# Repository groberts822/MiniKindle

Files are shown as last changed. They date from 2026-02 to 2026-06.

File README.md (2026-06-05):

# MiniKindle
A mini e-reader/kindle!
---
Final Design:





Final Build:



Demo:

https://youtube.com/shorts/sy03gHUxKEQ 

CAD Models:



Note for the CAD design. There are holes to connect the wires from the switch and TP4056 (the pos and neg) to the pins of the ESP32C3, its just hard to get a good picture of those. Also, the battery setup will be soldered to the 5V and GND pins of the microcontroller as the battery pads are covered by the case, and its simply easier to access the 5V pin, which works just fine as it can take the 3.7V down to the 3.3V fine.

Another note, the case will be assembled by using super glue to secure all 3D printed parts to one another. The PCB fits right into place and (should) fit securely enough to keep it in place without wiggling. 

Assembly:



Just a note, the eink display will be mounted to the board through the pins for the white connector. It may seem overly complicated, but i've done it for projects before and it's easier than it seems. It will simply be soldered from the pins there to the soldering holes using wires, as there isnt really an easier, compact way to connect it, and I just prefer this method.

Schematic:



PCB: 



3D of PCB with all Parts





Bill of Materials (also in .csv format)

| Item | Order Qty | Actual Amount Needed | Link |
|---|---|---|---|
| Seeed Studio XIAO ESP32C3 | 1 | 1 | [Amazon](https://www.amazon.com/Seeed-Studio-XIAO-ESP32C3-Microcontroller/dp/B0B94JZ2YF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) |
| Waveshare 2.13in E-Ink Display HAT | 1 | 1 | [Amazon](https://www.amazon.com/waveshare-2-13inch-HAT-Compatible-Resolution/dp/B071S8HT76/) |
| ANMBEST Micro SD Card Adapter | 1 pack (10pcs) | 1 | [Amazon](https://www.amazon.com/ANMBEST-Adapter-Interface-Conversion-Arduino/dp/B08CMLG4D6/) |
| DAOKI 6mm Tactile Push Buttons | 1 pack (100pcs) | 2 | [Amazon](https://www.amazon.com/DAOKI-Miniature-Momentary-Tactile-Quality/dp/B01CGMP9GY/) |
| MakerFocus 3.7V 1100mAh LiPo Battery | 1 pack (4pcs) | 1 | [Amazon](https://www.amazon.com/1100mAh-Rechargable-Protection-Insulated-Development/dp/B0867KDMY7/) |
| ALAMSCN TP4056 Type-C Charger | 1 pack (12pcs) | 1 | [Amazon](https://www.amazon.com/ALAMSCN-Lithium-Charging-Protection-Functions/dp/B08F7QSLN7/) |
| Mini Micro Slide Switch | 1 pack (20pcs) | 1 | [Amazon](https://www.amazon.com/Mini-Micro-Slide-Switch-Breadboard/dp/B0DN69L9SG/) |

------------------------------------------------------
I wanted a reading device which didn't feel like a smartphone. Most modern screens are meant to grab our attention with the backlight and notifications. This project is about the opposite, being a distraction-free and almost "offline" experience. This project uses an E-ink display and the text looks like actuasl paper and doesn't strain the eyes. Plus since the E-ink only uses power when the page changes initially, I can leave a book open for long periods of time without the battery dying. 

The brain of the project is a XIAO ESP32C3. When you flip the physical slide switch the system boots and reads the book files (.txt files) from the MicroSD card. There are 2 tactile buttons which allow you to essentially turn the page. It uses a 2.13-in electronic paper display (EPD) and is crisp in direct sunlight and stays on/displays text even after power is cut. A TP4056 module manages the 1100mAh LiPo battery, which you can charge via USB-C, and the slide switch makes sure the battery doesnt drain when the reader is not in use.

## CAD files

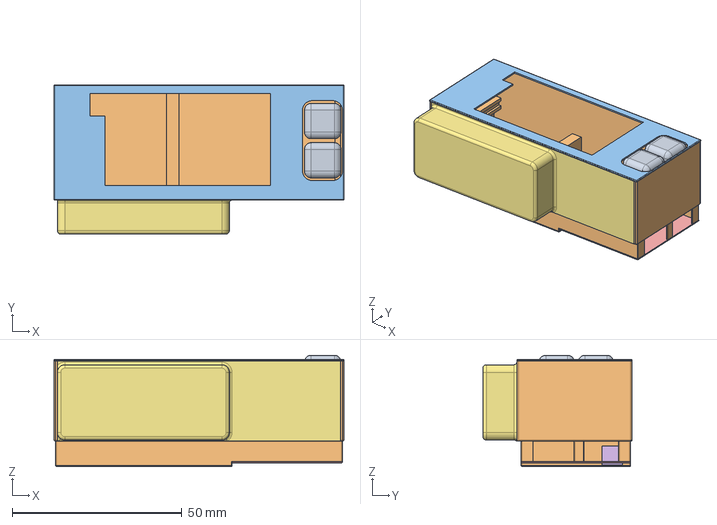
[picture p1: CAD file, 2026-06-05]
cad/Mini Kindle Assembled (No PCB or Parts).step
85.5 x 44.0 x 32.9 mm
SW_PUSH_6mm x 2

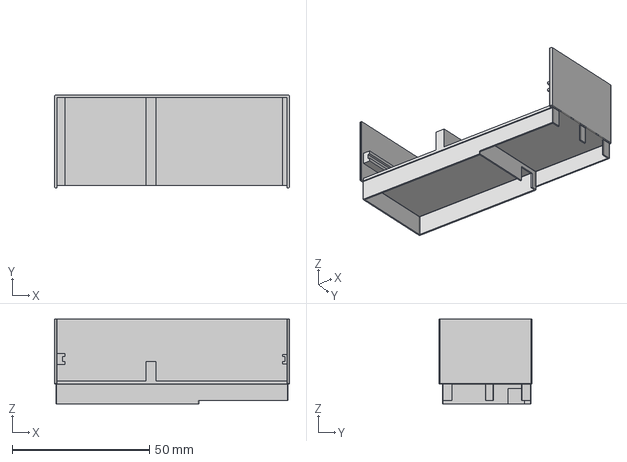
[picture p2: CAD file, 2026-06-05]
cad/Mini Kindle Main Body.step
85.5 x 34.0 x 30.8 mm

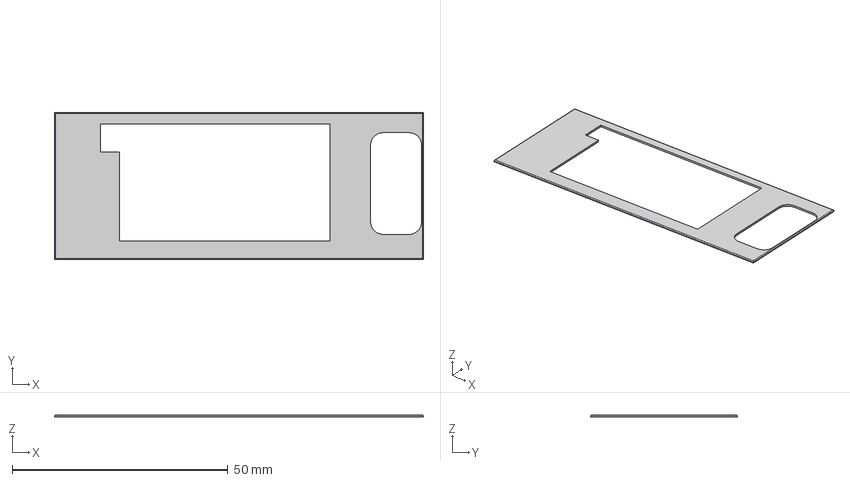
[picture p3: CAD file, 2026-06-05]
cad/Mini Kindle Top Cover.step
85.5 x 34.0 x 0.5 mm

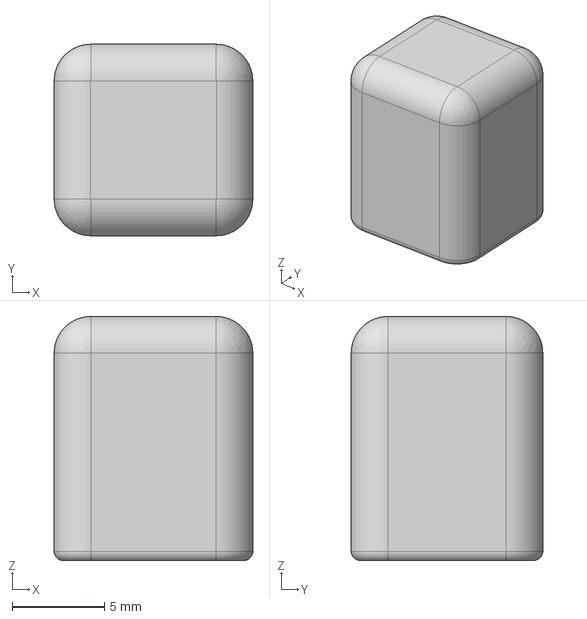
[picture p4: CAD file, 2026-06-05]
cad/Mini Kindle Button Cap.step
10.8 x 10.4 x 13.3 mm

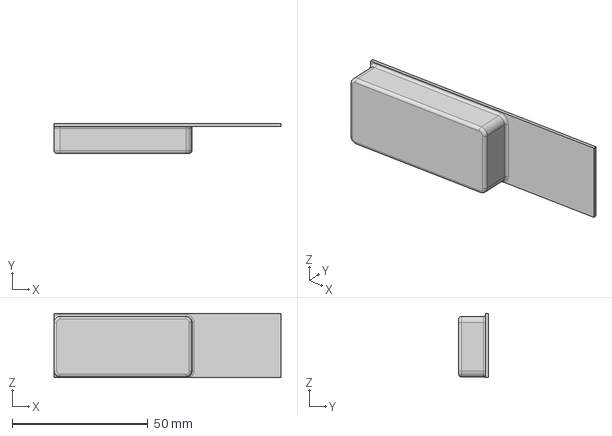
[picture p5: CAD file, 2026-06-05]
cad/Mini Kindle Front Side Cover.step
83.5 x 11.0 x 23.5 mm

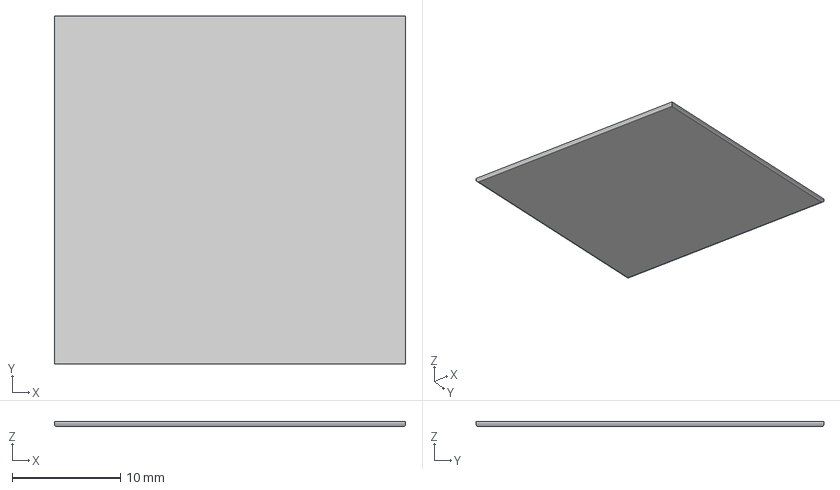
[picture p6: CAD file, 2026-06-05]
cad/Mini Kindle Switch + Charger Cover.step
32.5 x 32.2 x 0.5 mm

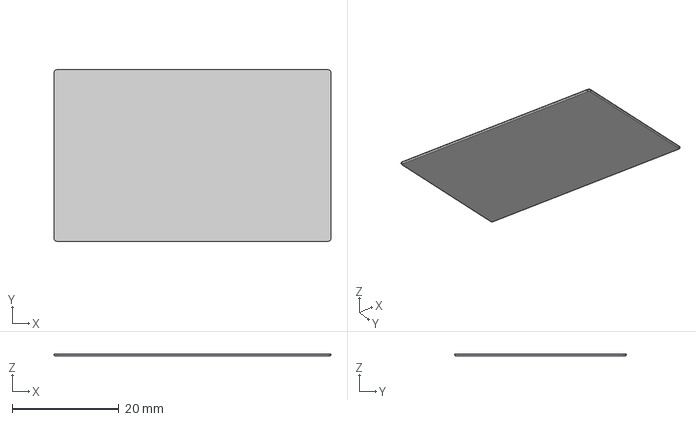
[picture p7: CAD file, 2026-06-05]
cad/Mini Kindle Battery Cover.step
52.0 x 32.2 x 0.4 mm

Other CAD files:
cad/Mini Kindle Assembled (No PCB or Parts).f3z
cad/Mini Kindle Assembled (with PCB + Parts).f3z

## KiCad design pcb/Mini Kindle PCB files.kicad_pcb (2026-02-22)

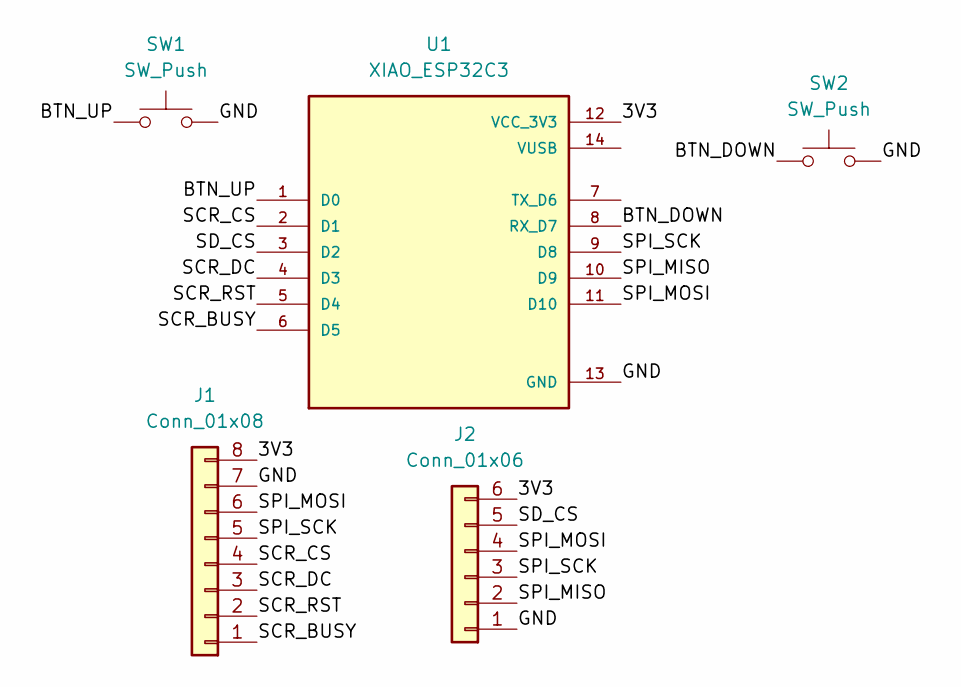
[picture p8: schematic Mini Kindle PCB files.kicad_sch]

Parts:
J1: Conn_01x08; PinHeader_1x08_P2.54mm_Vertical
J2: Conn_01x06; PinHeader_1x06_P2.54mm_Vertical
SW1, SW2: SW_Push; SW_PUSH_6mm
U1: XIAO_ESP32C3; MODULE_XIAO_ESP32C3; PARTREV 23/05/2022

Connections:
/3V3: J1.8, J2.6, U1.12 (VCC_3V3)
/BTN_DOWN: SW2.1, U1.8 (RX_D7)
/BTN_UP: SW1.1, U1.1 (D0)
/GND: J1.7, J2.1, SW1.2, SW2.2, U1.13 (GND)
/SCR_BUSY: J1.1, U1.6 (D5)
/SCR_CS: J1.4, U1.2 (D1)
/SCR_DC: J1.3, U1.4 (D3)
/SCR_RST: J1.2, U1.5 (D4)
/SD_CS: J2.5, U1.3 (D2)
/SPI_MISO: J2.2, U1.10 (D9)
/SPI_MOSI: J1.6, J2.4, U1.11 (D10)
/SPI_SCK: J1.5, J2.3, U1.9 (D8)

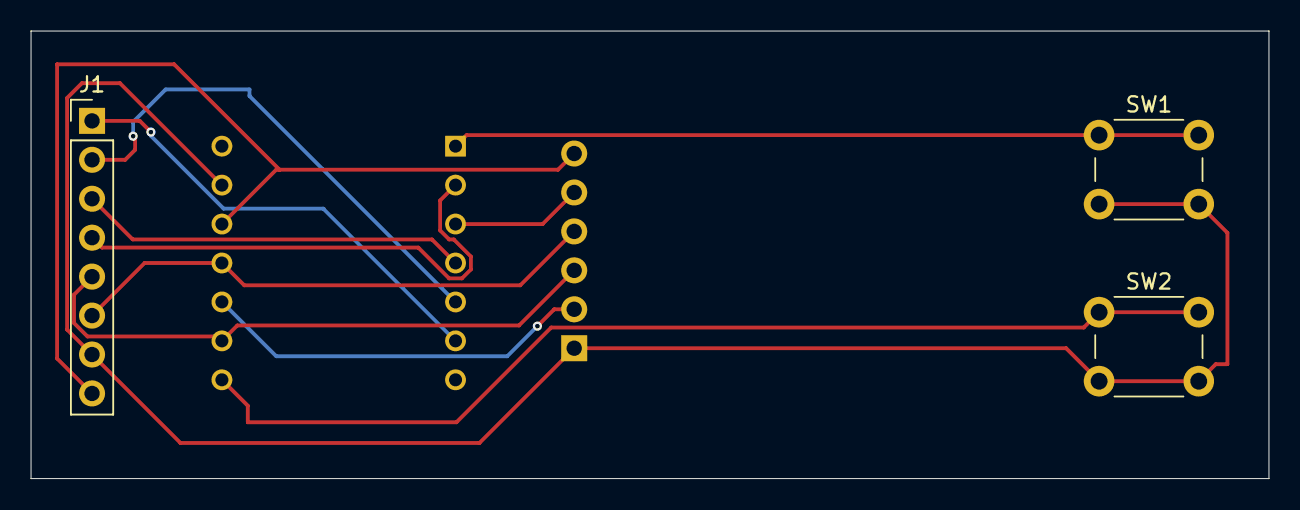
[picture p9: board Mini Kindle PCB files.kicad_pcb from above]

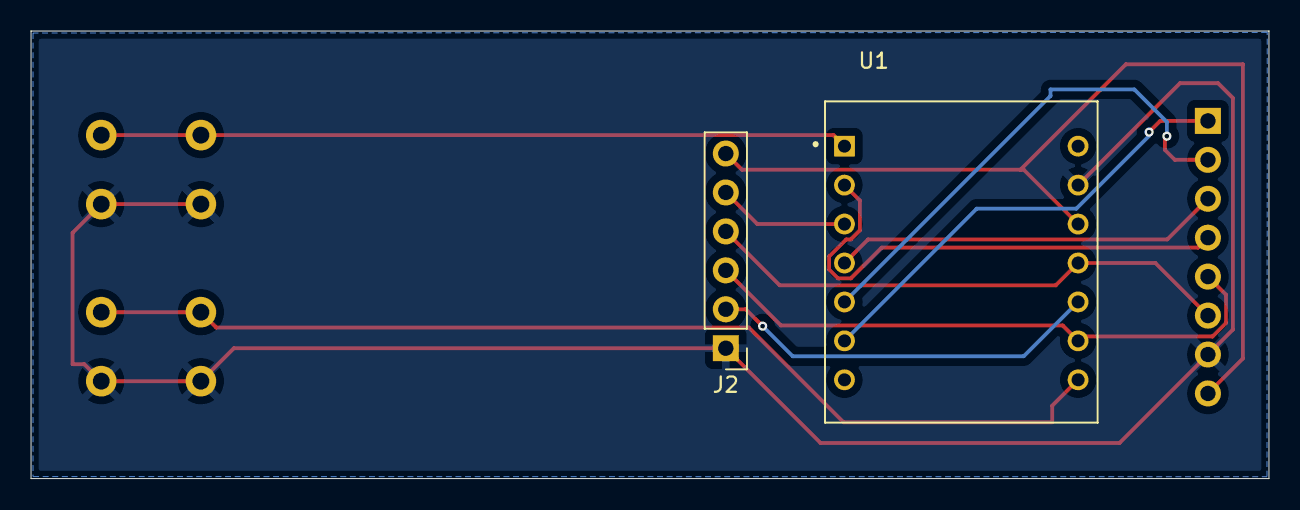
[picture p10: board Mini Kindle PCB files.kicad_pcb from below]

Board: 2 copper layers, 80.8 x 29.2 mm, 5 parts (2 on the bottom side), 12 nets.

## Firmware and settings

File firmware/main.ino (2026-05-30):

#include <GxEPD2_BW.h>
#include <SD.h>
#include <SPI.h>

#define SCREEN_CS   3
#define SCREEN_DC   5
#define SCREEN_RST  6
#define SCREEN_BUSY 7
#define SD_CS       4
#define SPI_MOSI    10
#define SPI_MISO    9
#define SPI_SCK     8
#define BTN_UP      2
#define BTN_DOWN    20

GxEPD2_BW<GxEPD2_213_BN, GxEPD2_213_BN::HEIGHT> display(
  GxEPD2_213_BN(SCREEN_CS, SCREEN_DC, SCREEN_RST, SCREEN_BUSY)
);

#define DISP_W 250
#define DISP_H 122

static const int ENTRY_ROW_TOP[6] = {14, 28, 42, 56, 70, 84};
static const int ENTRY_TEXT_Y[6]  = {17, 31, 45, 59, 73, 87};
#define MENU_ENTRIES   6
#define HDR_H         12
#define HDR_TY         2
#define HINT_TOP     112
#define HINT_TY      113

#define CHARS_PER_LINE 41
#define LINES_PER_PAGE 10
#define READ_LINE_H    11
#define READ_FIRST_Y    1
#define SCROLL_STEP     3

#define MAX_BOOKS 20
char bookNames[MAX_BOOKS][44];
char bookFiles[MAX_BOOKS][48];
int  bookCount   = 0;
int  menuIndex   = 0;
int  menuScroll  = 0;
int  readingBook = -1;

File bookFile;
long pageStart     = 0;
long prevPageStart = 0;

#define HOLD_MS     1800
#define DEBOUNCE_MS  30

struct Btn {
  bool     lastRaw;
  bool     confirmed;
  uint32_t downAt;
  bool     holdFired;
} bUp={}, bDown={};

uint8_t pollBtn(int pin, Btn &s) {
  bool raw = (digitalRead(pin) == LOW);

  if (raw && !s.lastRaw) {
    s.downAt    = millis();
    s.confirmed = false;
    s.holdFired = false;
  }

  if (raw && !s.confirmed && (millis() - s.downAt > DEBOUNCE_MS)) {
    s.confirmed = true;
  }

  if (s.confirmed && !s.holdFired && (millis() - s.downAt >= HOLD_MS)) {
    s.holdFired = true;
    s.lastRaw   = raw;
    return 2;
  }

  if (!raw && s.lastRaw) {
    bool fire = s.confirmed && !s.holdFired;
    s.confirmed = false;
    s.holdFired = false;
    s.lastRaw   = false;
    return fire ? 1 : 0;
  }

  s.lastRaw = raw;
  return 0;
}

void stemToTitle(const char *stem, char *out, int maxLen) {
  int i = 0;
  while (stem[i] && i < maxLen - 1) {
    out[i] = (stem[i] == '_') ? ' ' : stem[i];
    i++;
  }
  out[i] = '\0';
}

void showMessage(const char *l1, const char *l2 = nullptr) {
  display.setFullWindow();
  display.firstPage();
  do {
    display.fillScreen(GxEPD_WHITE);
    display.setTextColor(GxEPD_BLACK);
    display.setCursor(5, 20);
    display.print(l1);
    if (l2) { display.setCursor(5, 36); display.print(l2); }
  } while (display.nextPage());
}

void drawSplash() {
  display.setFullWindow();
  display.firstPage();
  do {
    display.fillScreen(GxEPD_WHITE);

    
    display.drawRect(0, 0, DISP_W, DISP_H, GxEPD_BLACK);
    display.drawRect(3, 3, DISP_W-6, DISP_H-6, GxEPD_BLACK);

    
    int bx=14, by=12, bw=40, bh=52;
    display.fillRect(bx+3, by+3, bw, bh, GxEPD_BLACK);   // shadow
    display.fillRect(bx, by, bw, bh, GxEPD_WHITE);
    display.drawRect(bx, by, bw, bh, GxEPD_BLACK);
    display.fillRect(bx, by, 5, bh, GxEPD_BLACK);         // spine
    display.drawFastVLine(bx+bw-3, by+2, bh-4, GxEPD_BLACK); // page stack
    display.drawFastVLine(bx+bw-5, by+2, bh-4, GxEPD_BLACK);
    for (int li=0; li<5; li++) {                           // cover lines
      int lw = (li==0)?24:(li%2==0?18:14);
      display.fillRect(bx+8, by+8+li*8, lw, 2, GxEPD_BLACK);
    }
    display.setCursor(bx+22, by+bh-10);
    display.print("mk");

    
    display.setCursor(72, 20);  display.print("m  i  n  i");
    display.fillRect(72, 31, 162, 2, GxEPD_BLACK);
    display.setCursor(72, 35);  display.print("K  I  N  D  L  E");
    display.setCursor(72, 52);  display.print("distraction-free");
    display.setCursor(72, 64);  display.print("e-reader");
    display.setCursor(72, 80);  display.print("by groberts822");

    display.fillRect(6, DISP_H-9, DISP_W-12, 2, GxEPD_BLACK);

  } while (display.nextPage());
  delay(3000);
}

void discoverBooks() {
  bookCount = 0;
  File root = SD.open("/");
  while (bookCount < MAX_BOOKS) {
    File e = root.openNextFile();
    if (!e) break;
    if (e.isDirectory()) { e.close(); continue; }
    const char *name = e.name();
    int len = strlen(name);
    if (len > 4 && name[0] != '.' &&
        tolower(name[len-4])=='.' && tolower(name[len-3])=='t' &&
        tolower(name[len-2])=='x' && tolower(name[len-1])=='t') {
      snprintf(bookFiles[bookCount], 48, "/%s", name);
      char stem[44]; int sl=len-4; if(sl>43)sl=43;
      strncpy(stem, name, sl); stem[sl]='\0';
      stemToTitle(stem, bookNames[bookCount], 44);
      bookCount++;
    }
    e.close();
  }
  root.close();
}

void drawMenu() {
  if (menuIndex < menuScroll) menuScroll = menuIndex;
  if (menuIndex >= menuScroll + MENU_ENTRIES)
    menuScroll = menuIndex - MENU_ENTRIES + 1;

  display.setFullWindow();
  display.firstPage();
  do {
    display.fillScreen(GxEPD_WHITE);

    
    display.fillRect(0, 0, DISP_W, HDR_H, GxEPD_BLACK);
    display.setTextColor(GxEPD_WHITE);
    display.setCursor(6, HDR_TY);
    display.print("MK LIBRARY");
    char cnt[12]; snprintf(cnt, 12, "%d books", bookCount);
    display.setCursor(DISP_W - (int)strlen(cnt)*6 - 4, HDR_TY);
    display.print(cnt);
    display.setTextColor(GxEPD_BLACK);

  
    for (int i = 0; i < MENU_ENTRIES; i++) {
      int bi = menuScroll + i;
      if (bi >= bookCount) break;

      if (bi == menuIndex) {
        display.fillRect(0, ENTRY_ROW_TOP[i], DISP_W, 14, GxEPD_BLACK);
        display.setTextColor(GxEPD_WHITE);
        display.setCursor(8, ENTRY_TEXT_Y[i]);
        display.print(bookNames[bi]);
        display.setTextColor(GxEPD_BLACK);
      } else {
        display.setCursor(8, ENTRY_TEXT_Y[i]);
        display.print(bookNames[bi]);
      }
    }

    
    display.fillRect(0, HINT_TOP, DISP_W, DISP_H-HINT_TOP, GxEPD_BLACK);
    display.setTextColor(GxEPD_WHITE);
    display.setCursor(6, HINT_TY);
    display.print("UP/DN:scroll  Hold UP:open");
    display.setTextColor(GxEPD_BLACK);

  } while (display.nextPage());
}

void renderPage(int scrollLines) {
  prevPageStart = pageStart;
  bookFile.seek(pageStart);

  const int BUF = LINES_PER_PAGE + 4;
  String lines[BUF];
  int lc = 0;
  String cur = "";

  while (lc < BUF && bookFile.available()) {
    char c = bookFile.read();
    if (c == '\r') continue;
    if (c == '\n') { lines[lc++] = cur; cur = ""; continue; }
    cur += c;
    if ((int)cur.length() >= CHARS_PER_LINE) {
      int sp = cur.lastIndexOf(' ');
      if (sp > 0) {
        lines[lc++] = cur.substring(0, sp);
        String ov = cur.substring(sp+1);
        bookFile.seek(bookFile.position() - ov.length());
        cur = "";
      } else { lines[lc++] = cur; cur = ""; }
    }
  }
  if (lc < BUF && cur.length() > 0) lines[lc++] = cur;

  if (scrollLines > 0) {
    bookFile.seek(pageStart);
    int skipped = 0; String tmp = "";
    while (skipped < scrollLines && bookFile.available()) {
      char c = bookFile.read();
      if (c == '\r') continue;
      if (c == '\n') { skipped++; tmp=""; continue; }
      tmp += c;
      if ((int)tmp.length() >= CHARS_PER_LINE) {
        int sp = tmp.lastIndexOf(' ');
        if (sp > 0) {
          skipped++;
          String ov = tmp.substring(sp+1);
          bookFile.seek(bookFile.position() - ov.length());
          tmp = "";
        } else { skipped++; tmp=""; }
      }
    }
    pageStart = bookFile.position();
  }

  display.setFullWindow();
  display.firstPage();
  do {
    display.fillScreen(GxEPD_WHITE);
    display.setTextColor(GxEPD_BLACK);
    for (int i = 0; i < LINES_PER_PAGE && i < lc; i++) {
      display.setCursor(2, READ_FIRST_Y + i * READ_LINE_H);
      display.print(lines[i]);
    }
    
    if (bookFile.size() > 0) {
      int barW = (int)((float)pageStart / bookFile.size() * (DISP_W-4));
      display.drawFastHLine(2, 119, DISP_W-4, GxEPD_BLACK);
      display.fillRect(2, 119, barW, 2, GxEPD_BLACK);
    }
  } while (display.nextPage());
}

void setup() {
  Serial.begin(115200);
  delay(300);
  pinMode(BTN_UP,   INPUT_PULLUP);
  pinMode(BTN_DOWN, INPUT_PULLUP);
  SPI.begin(SPI_SCK, SPI_MISO, SPI_MOSI);
  display.init(115200, true, 50, false);
  display.setRotation(3);
  display.setFont(NULL);
  display.setTextSize(1);
  display.setTextColor(GxEPD_BLACK);
  display.setTextWrap(false);
  drawSplash();
  showMessage("Loading...");
  if (!SD.begin(SD_CS, SPI)) {
    showMessage("SD Card Failed", "Check wiring");
    while (true);
  }
  discoverBooks();
  if (bookCount == 0) {
    showMessage("No .txt files", "found on SD card");
    while (true);
  }
  drawMenu();
}

void loop() {
  uint8_t up   = pollBtn(BTN_UP,   bUp);
  uint8_t down = pollBtn(BTN_DOWN, bDown);

  if (readingBook < 0) {
    
    if      (up   == 1) { menuIndex = (menuIndex - 1 + bookCount) % bookCount; drawMenu(); }
    else if (down == 1) { menuIndex = (menuIndex + 1) % bookCount;              drawMenu(); }
    else if (up   == 2) {
      readingBook = menuIndex;
      pageStart = prevPageStart = 0;
      bookFile = SD.open(bookFiles[readingBook]);
      if (!bookFile) {
        showMessage("Failed to open", bookFiles[readingBook]);
        readingBook = -1; drawMenu(); return;
      }
      renderPage(0);
    }
  } else {
    
    if (down == 1) {
      if (bookFile.available()) renderPage(SCROLL_STEP);
      else showMessage("End of book.", "Hold DOWN:menu");
    }
    else if (up   == 1) { pageStart = prevPageStart; bookFile.seek(pageStart); renderPage(0); }
    else if (down == 2) { bookFile.close(); readingBook = -1; drawMenu(); }
  }
}
